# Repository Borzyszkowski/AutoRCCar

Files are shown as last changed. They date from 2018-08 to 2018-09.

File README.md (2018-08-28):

## Robotics in India: Intelligent Robot, Remote/Self-Driving Car
### by Bartłomiej Borzyszkowski, Poland
### Gdansk University of Technology (ETI) | Karunya Institute of Technology and Sciences (ET)

##### Python3 + OpenCV, Neural Networks, Raspberry Pi, Arduino Uno, Motor Driver, PiCamera, Ultrasonic sensor
##### Origin and inspiration for the project: https://github.com/hamuchiwa/AutoRCCar

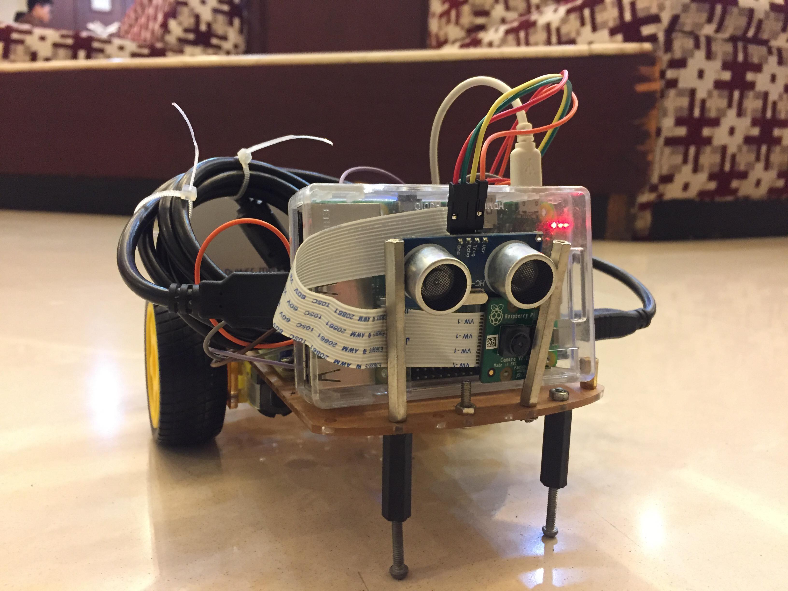
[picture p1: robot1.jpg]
robot

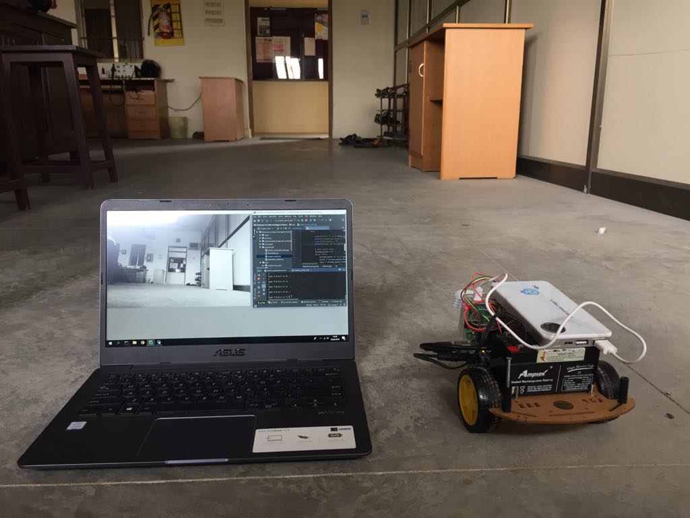
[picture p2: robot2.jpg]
computer+robot

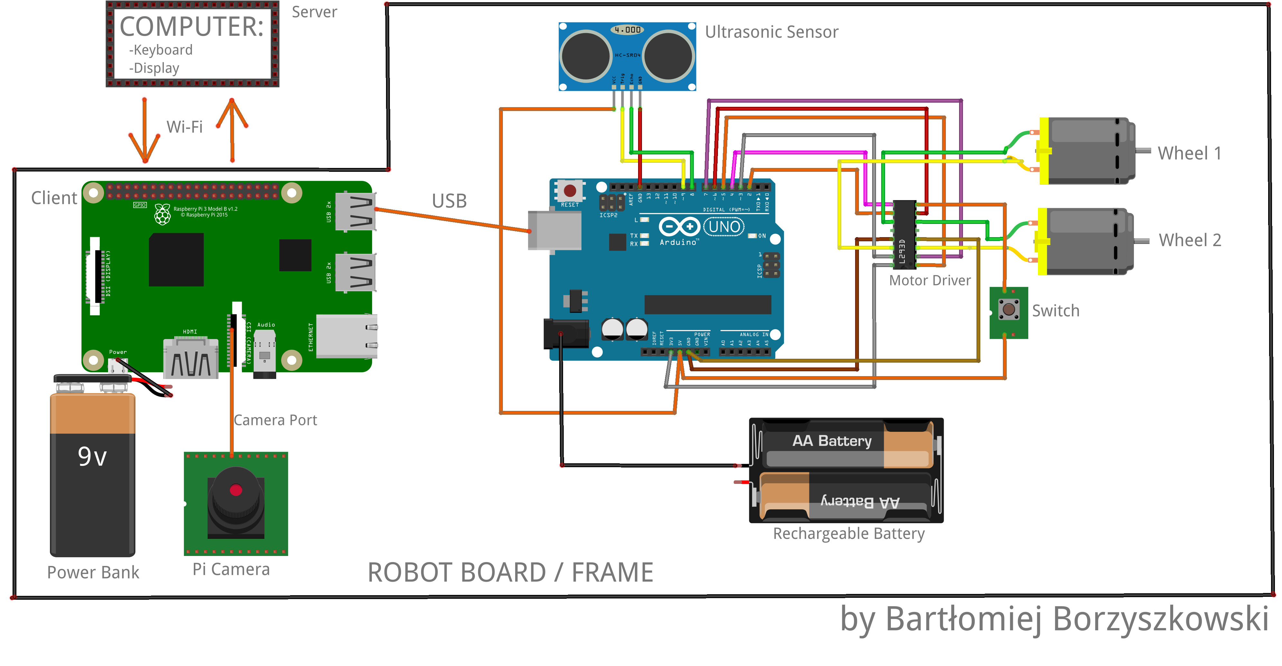
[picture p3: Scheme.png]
Scheme


This project builds a self-driving RC car using Raspberry Pi, Arduino and open source software. Raspberry Pi collects inputs from a camera module and an ultrasonic sensor, and sends data to a computer wirelessly. The computer processes input images and sensor data for object detection (stop sign and traffic light) and collision avoidance respectively. A neural network model runs on computer and makes predictions for steering based on input images. Predictions are then sent to the Arduino for RC car control. 
  
### For more information and details visit the folder "Multimedia and Sources".
### Don't stray too far from the presentation "Robotics in India" which explains the project.
[Presentation Robotics in India](https://github.com/Borzyszkowski/Robotics-in-India-Intelligent-Robot/blob/master/Multimedia%20and%20Sources/Robotics%20in%20India%20presentation.pdf)
 
### Setting up environment with Anaconda
  1. Install [`miniconda`](https://conda.io/miniconda.html) on your computer
  2. Create `auto-rccar` environment with all necessary libraries for this project  
     ```conda env create -f environment.yml```
     
  3. Activate `auto-rccar` environment  
     ```source activate auto-rccar```
  
  &ensp; To exit, simply close the terminal window. More info about managing Anaconda environment, please see [here](https://conda.io/docs/user-guide/tasks/manage-environments.html).
  
### About the files
**test/**  
  &emsp; &emsp; `rc_control_test.py`: RC car control with keyboard  
  &emsp; &emsp;  `stream_server_test.py`: video streaming from Pi to computer  
  &emsp; &emsp;  `ultrasonic_server_test.py`: sensor data streaming from Pi to computer  
  &emsp; &emsp;  **model_train_test/**  
      &emsp; &emsp;  &emsp; &emsp; `data_test.npz`: sample data  
      &emsp; &emsp;  &emsp; &emsp; `train_predict_test.ipynb`: a jupyter notebook that goes through neural network model in OpenCV3  
  
**raspberryPi/**    
  &emsp; &emsp;  `stream_client.py`:        stream video frames in jpeg format to the host computer  
  &emsp; &emsp;  `ultrasonic_client.py`:    send distance data measured by sensor to the host computer  
  
**arduino/**  
  &emsp; &emsp;  `rc_keyboard_control.ino`: control RC car controller  
  
**computer/**    
  &emsp; &emsp;  **cascade_xml/**  
      &emsp; &emsp;  &emsp; &emsp;  trained cascade classifiers  
  &emsp; &emsp;  **chess_board/**   
      &emsp; &emsp;  &emsp; &emsp;  images for calibration, captured by pi camera  
      
  &emsp; &emsp;  `picam_calibration.py`:     pi camera calibration  
  &emsp; &emsp;  `collect_training_data.py`: collect images in grayscale, data saved as `*.npz`  
  &emsp; &emsp;  `model.py`:                 neural network model  
  &emsp; &emsp;  `model_training.py`:        model training and validation  
  &emsp; &emsp;  `rc_driver_helper.py`:      helper classes/functions for `rc_driver.py`  
  &emsp; &emsp;  `rc_driver.py`:             receive data from raspberry pi and drive the RC car based on model prediction
  
**Traffic_signal**  
  &emsp; &emsp;  trafic signal sketch contributed by [@geek111](https://github.com/geek1111)

### How to drive
1. **Testing:** Flash `rc_keyboard_control.ino` to Arduino and run `rc_control_test.py` to drive the RC car with keyboard. Run `stream_server_test.py` on computer and then run `stream_client.py` on raspberry pi to test video streaming. Similarly, `ultrasonic_server_test.py` and `ultrasonic_client.py` can be used for sensor data streaming testing.   

2. **Pi Camera calibration (optional):** Take multiple chess board images using pi camera module at various angles and put them into **`chess_board`** folder, run `picam_calibration.py` and returned parameters from the camera matrix will be used in `rc_driver.py`.

3. **Collect training/validation data:** First run `collect_training_data.py` and then run `stream_client.py` on raspberry pi. Press arrow keys to drive the RC car, press `q` to exit. Frames are saved only when there is a key press action. Once exit, data will be saved into newly created **`training_data`** folder.

4. **Neural network training:** Run `model_training.py` to train a neural network model. Please feel free to tune the model architecture/parameters to achieve a better result. After training, model will be saved into newly created **`saved_model`** folder.

5. **Cascade classifiers training (optional):** Trained stop sign and traffic light classifiers are included in the **`cascade_xml`** folder, if you are interested in training your own classifiers, please refer to [OpenCV doc](http://docs.opencv.org/doc/user_guide/ug_traincascade.html) and this great [tutorial](http://coding-robin.de/2013/07/22/train-your-own-opencv-haar-classifier.html).

6. **Self-driving in action**: First run `rc_driver.py` to start the server on the computer, and then run `stream_client.py` and `ultrasonic_client.py` on raspberry pi.

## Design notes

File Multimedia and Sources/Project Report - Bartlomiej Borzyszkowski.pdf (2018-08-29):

DEVELOPMENT OF AN INTELLIGENT,

## REMOTE / SELF-DRIVING CAR

An IAESTE Internship Project Report submitted by

### BARTŁOMIEJ BORZYSZKOWSKI (IS18ET019)

Under the supervision of
Dr. K. Rajasekaran,
M.Tech., Ph.D., Professor

With the assistance of
Mr. J. Chinnadurai,

D.E.E.E

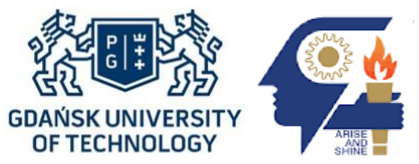
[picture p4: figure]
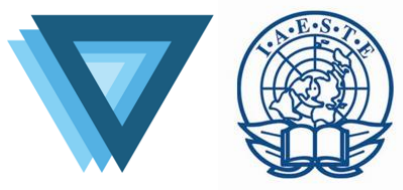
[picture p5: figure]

DEPARTMENT OF INSTRUMENTATION ENGINEERING

AUGUST 2018

BONAFIDE CERTIFICATE

This is to certify that this report entitled, “ CREATING AND DEVELOPING OF THE INTELLIGENT ROBOT, REMOTE / SELF-DRIVING CAR”, is a bonafide work of the following candidate from Gdansk University of Technology, Poland, who carried out the IAESTE Internship project work under my supervision during the academic year 2018-19 / Summer 2018.

BARTŁOMIEJ BORZYSZKOWSKI (IS18ET019)

Dissertation submitted in partial fulfillment of the requirements for the completion of the

IAESTE INTERNSHIP PROJECT

DEPARTMENT OF INSTRUMENTATION ENGINEERING

Supervisor
Dr. K. Rajasekaran,
M.Tech., Ph.D., Professor
Department of Instrumentation Engineering School of Engineering & Technology Karunya Institute of Technology and Sciences (A Deemed University)
Karunya Nagar, Coimbatore – 641 114

### ACKNOWLEDGEMENT

At the outset I express my gratitude to our eminent Professors – Prof. D.Sc. Ph.D. M.Sc.E.E. Jerzy Wtorek – Dean of the Faculty of Electronics,
Telecommunications and Informatics (https://pg.edu.pl/eti) and | | Prof. D.Sc. Ph.D. M.Sc.E.E.
Zdzisław Kowalczuk – Head of the Department | of Decision Systems and
Robotics (https://pg.edu.pl/katedra-systemow-decyzyjnych-i-robotyki) of Gdansk University of Technology, Poland for helping me in getting the Internship in India.

I thank IAESTE Poland, all the members of association and Gradient AI Science Club for their engagement, dedication and support in the project.

I wish to thank with deep sense of acknowledge to the Founders and Management of Karunya Institute of Technology & Sciences, Coimbatore for extending all facilities, providing me the educative infrastructure and learning ambience, which motivated me to a great extent.

I wish to express my sincere thanks to Dr. J. Dinesh Peter, Associate Professor, Head – IAESTE and Dr. P. Subha Hency Jose, Professor & Head of the Department of Instrumentation Engineering for their excellent encouragements in course of this work.

I take immense pleasure in conveying my thanks and deep sense of gratitude to my Supervisor Dr. K. Rajasekaran, Professor at the Department of Instrumentation Engineering, for his exhilarating supervision, timely suggestions and encouragement during all phases of this work. Also, I would like to thank all the Teaching faculty members and Supporting staff of our department for advising me whenever in need, cooperating with me and arranging the necessary facilities.

I would like to convey gratitude to my Parents whose support was always with me. Last but not the least I would like to thank my Friends and Others who directly or indirectly helped me in successful completion of this work.

IAESTE INTERNSHIP 2018

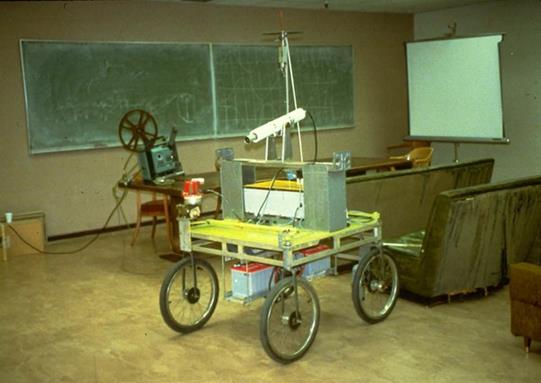
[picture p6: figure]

Department of IE / KITS, Coimbatore, India | Page 1

Abstract

Self-driving cars are vehicles in which human drivers are not required to take control to safely operate the vehicle. Also known as autonomous or „driverless” cars, they combine various sensors and software to control, navigate, and drive the vehicle. Self-driving technology is becoming increasingly common and could radically transform our transportation system (and by extension, our economy and society). The costs and benefits of self-driving cars are still largely hypothetical but in the past several years autonomous driving technologies have made a significant develop, giving a number of perspectives for the further progress.

Figure 1: Stanford Cart (1961) – the first „autonomous” vehicle

The idea of intelligent vehicle is multi-level, complex and contains a big number of different aspects. More information is needed to fully assess how autonomous cars impact drivers, the economy, equity environmental and public health. Recently, thanks to the artificial intelligence and deep learning methods, software engineers are able to develop solutions which give an answer for the big number of questions and difficulties.

As a result people create cars having different levels of intelligence and working with a diverse systems, sensors and environments. Partially-autonomous vehicles may require a human driver to intervene if the system encounters uncertainty or if the user simply wants to steer; fully-autonomous vehicles may not even offer a steering wheel.

Self-driving cars can be further distinguished as being „connected” or not, indicating whether they can communicate with other vehicles and/or infrastructure, such as next generation traffic lights.

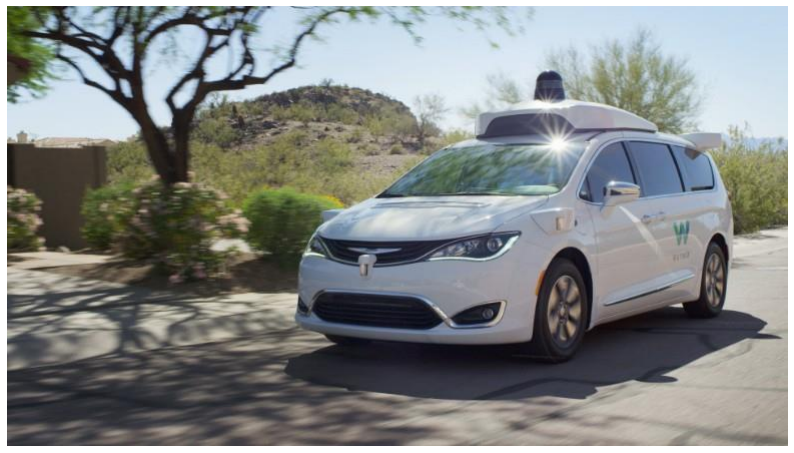
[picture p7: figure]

Figure 2: Waymo/Google – one of the most advanced self-driving cars

To make the development of self-driving cars easier, low cost, more accessible and prosperous small size models are widly used for the testing purposes. This solution guarantee the possibility to write the software working in the same way as in the real size models, compare the results and eliminate potential mistakes.

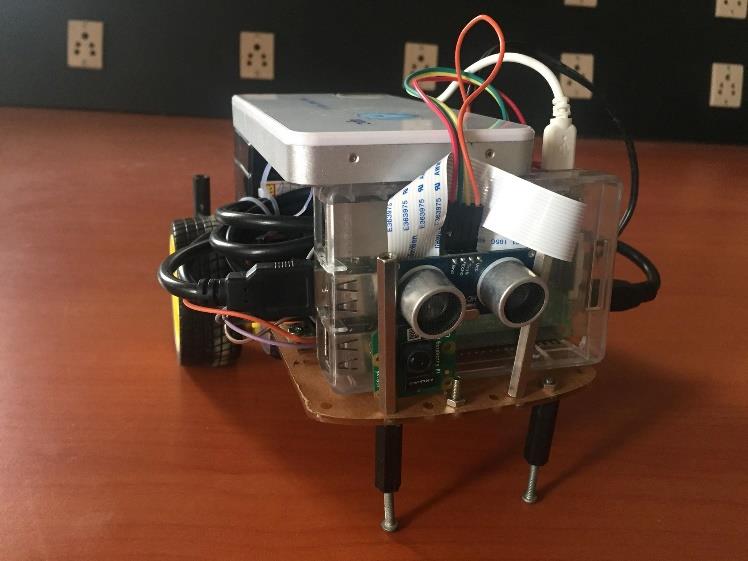
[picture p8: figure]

Figure 3: Intelligent Car project by Bartłomiej Borzyszkowski

Aim of the work

The aim of this project is to develop the model of partially-autonomous vehicle and reach the full-autonomous after future extensions.

The goal of the research is to design the construction of the intelligent car by using the Raspberry Pi, Arudino, ultrasonic sensor, camera and motor driver. Moreover, to write and develop the intelligent software using Python and C/C++ languages and design the „client – server” architecture between the used devices.

Robot overview

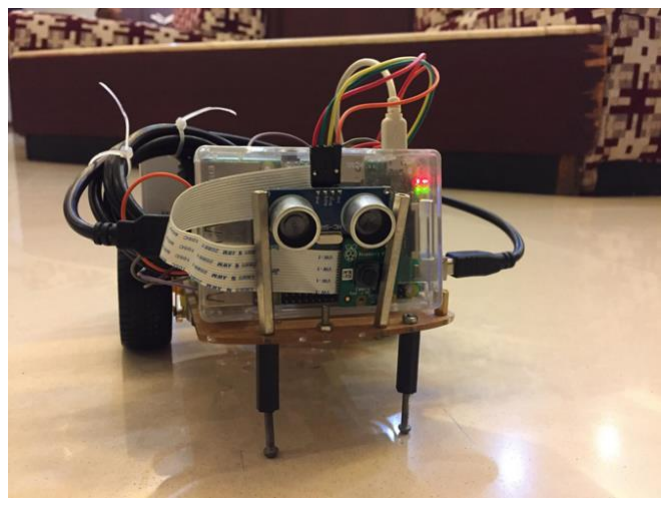
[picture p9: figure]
Equipment / C; omponents
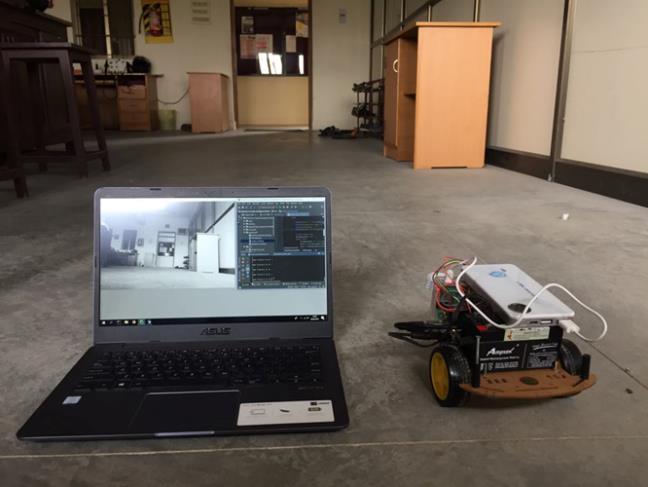
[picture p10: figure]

Figure 1: Front | Figure 2: Back and display

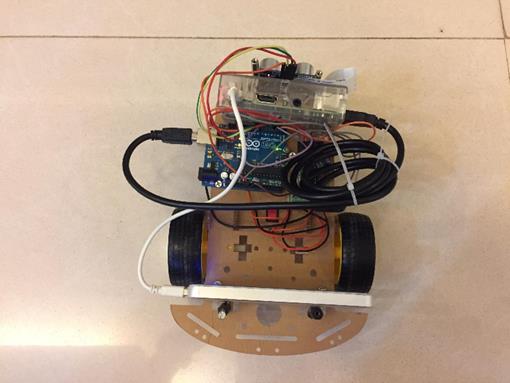
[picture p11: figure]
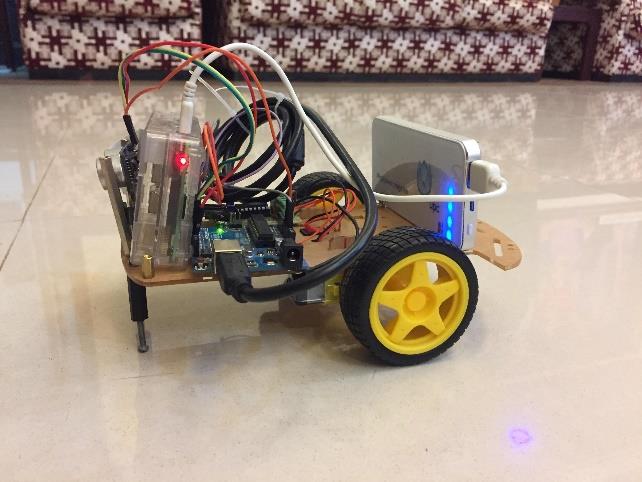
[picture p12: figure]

Figure 3: Top | Figure 4: Side

Project repository

The complete project repository, including the software, programs and libraries, multimedia and sources (videos and pictures from the laboratory), explanation of the project, schemes, problem solutions, robot construction and description of every particular device in the project is free and open to access, available on the GitHub profile under the link below:

github.com/Borzyszkowski/Robotics-in-India-Intelligent-Robot

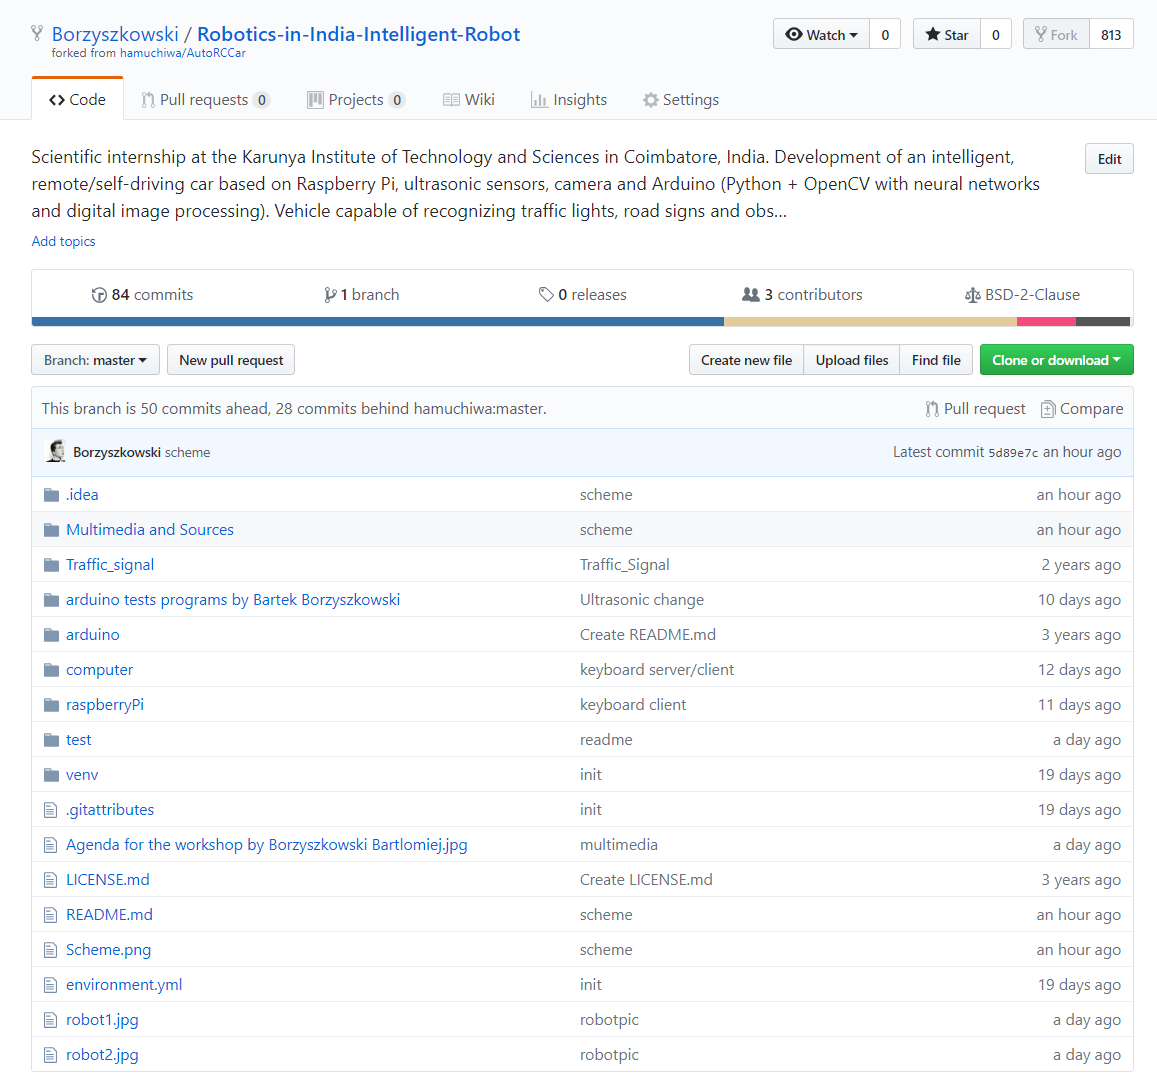
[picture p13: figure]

The project was inspired by the construction of autonomous car developed by Zheng Wang, available in the document below:

zhengludwig.wordpress.com/projects/self-driving-rc-car/

Functionality

The robot is an intelligent, partially-autonomous car, what means that user’s interve is required in the process but at the same time information collected from the environment make the robot capable to decide on its own and take some actions by itself.
The vehicle is able to move in four different directions – forward, backward, right, left and stop after pressing a corresponding button. The main functionality is steering by the user from the laptop keyboard (wireless connection/remote control).
Furthermore, the equipment with the ultrasonic sensor enables the robot to measure the distance from obstracles in the front and stop in case of possible collision. Thanks to the Pi camera the user has a real time display from the front of the robot on the laptop/PC screen. This solution allows the robot to be independent and wireless but at once the user has an access to steer the robot. In following steps of the project total autonomous and possibility to choose between self-drive or remote control steering is also possible.

Equipment / Components
- Raspberry Pi 3 Model B
- Camera desired for the Raspberry Pi
- Arduino UNO
- Laptop/PC
- Ultrasonic sensor HC-SR04
- Motor driver L293
- 2 separate motors and 2 wheels
- Power supply (power bank and an additional rechargeable battery)
- Robot board – car frame
- Cords/wires
- Switch button
- Soldering equipement
- Wi-Fi network
- External display
- Programming environment and software

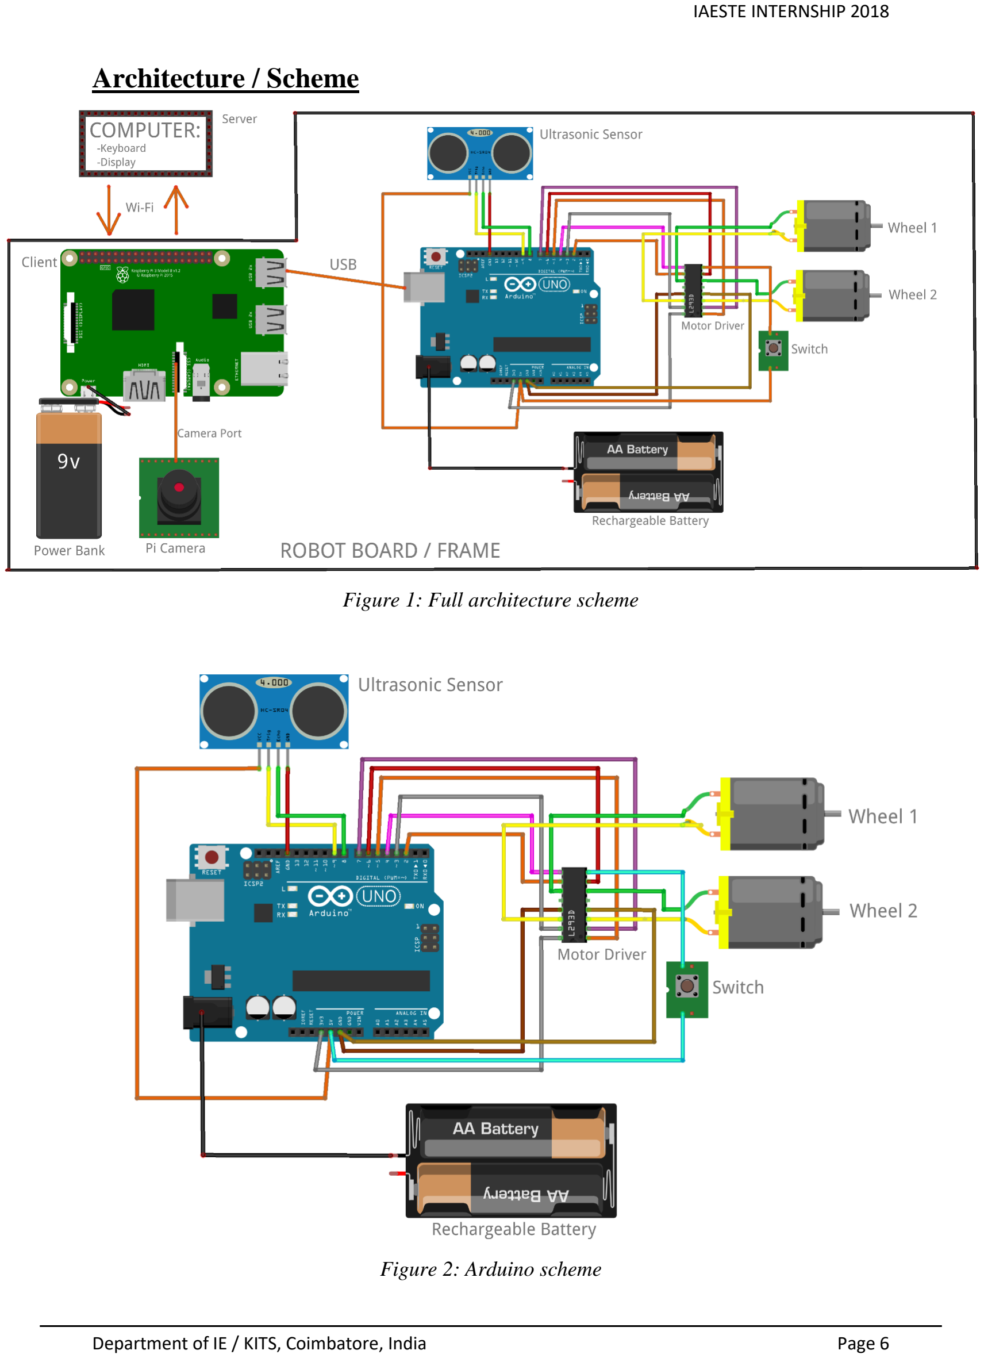
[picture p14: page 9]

Architecture / Scheme

Figure 1: Full architecture scheme

Figure 2: Arduino scheme

Hardware description

### 1. Computer

- Working as a server for the Raspberry Pi (client) via Wi-Fi
- Collecting information about steering from the keyboard and forwarding it to the Raspberry Pi
- Receiving video from the Raspberry Pi and showing the display

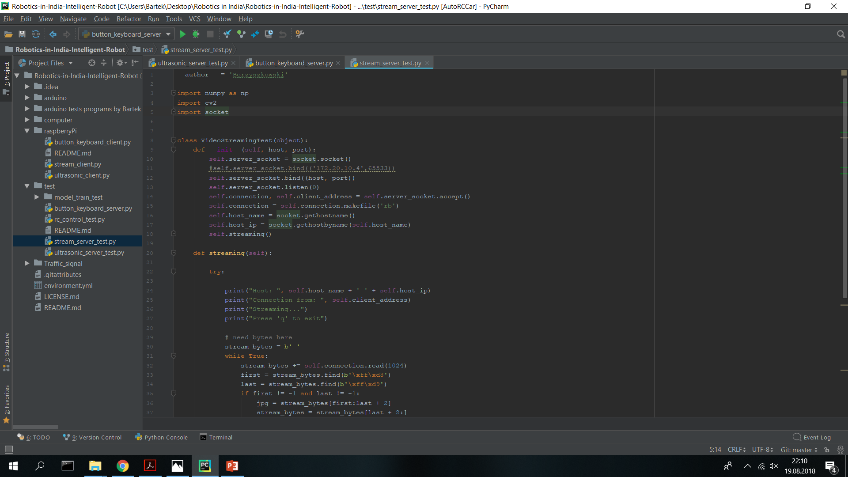
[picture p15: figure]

Figure 1: PyCharm Python Environment

### 2. Raspberry Pi

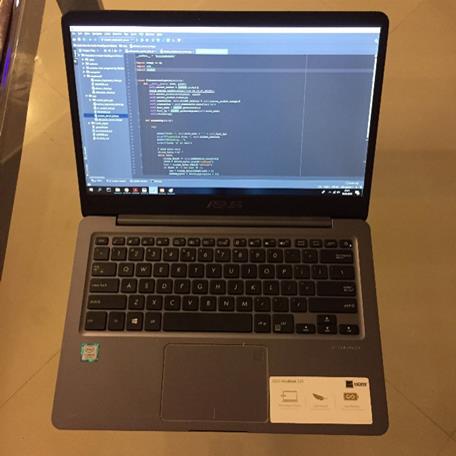
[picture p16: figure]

- Working as a client for the computer (server) via Wi-Fi
- Connected to the Arduino via USB
- Connected with the Pi camera
- Collecting information about steering from the computer (keyboard) and forwarding it to the Arduino
- Collecting data from the camera and sending it to the computer

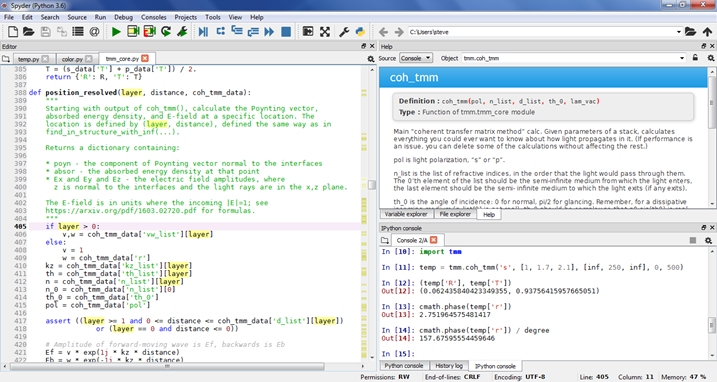
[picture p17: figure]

Figure 3: Spyder Python Environment

Figure 2: laptop used for the project

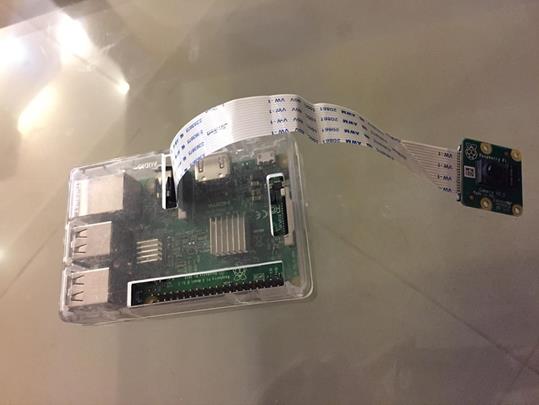
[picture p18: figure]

Figure 4: Raspberry Pi 3 model B with Pi Camera

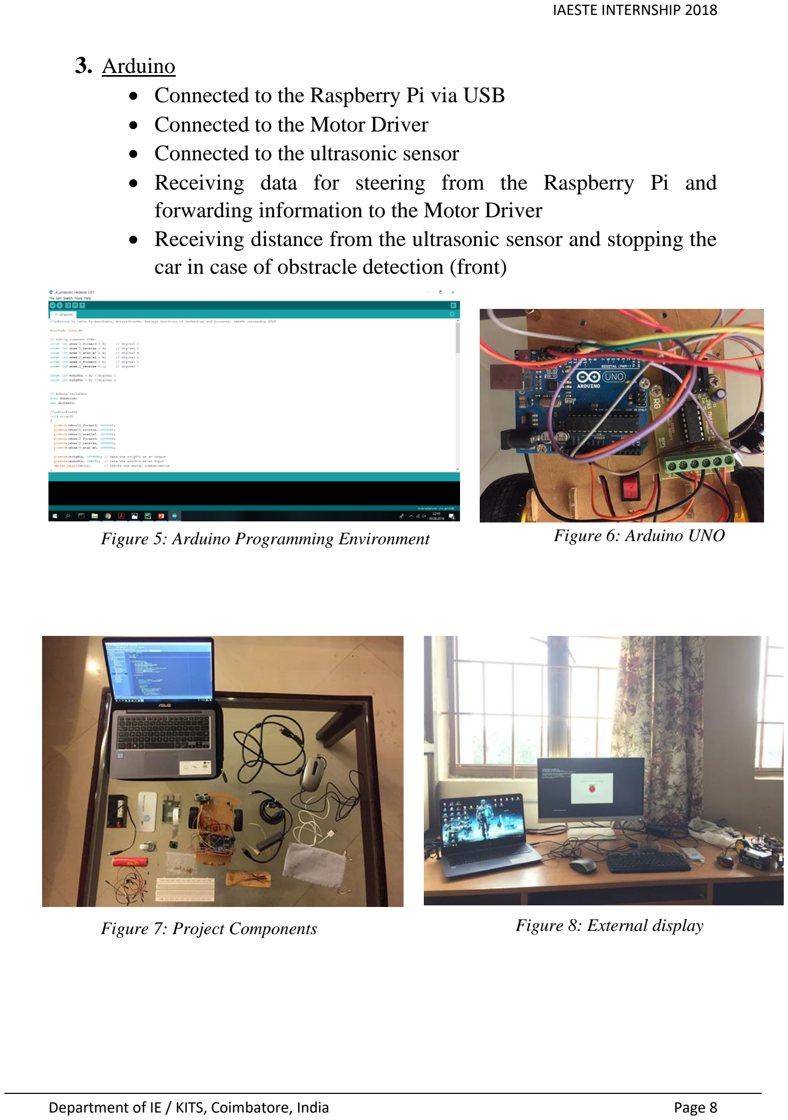
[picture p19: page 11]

### 3. Arduino

- Connected to the Raspberry Pi via USB
- Connected to the Motor Driver
- Connected to the ultrasonic sensor
- Receiving data for steering from the Raspberry Pi and forwarding information to the Motor Driver
- Receiving distance from the ultrasonic sensor and stopping the car in case of obstracle detection (front)

Figure 5: Arduino Programming Environment

Figure 7: Project Components

Figure 6: Arduino UNO

Figure 8: External display

Software description

In the current project version to achieve the required result five programs should run in the same time:

- Computer:
1. „button_keyboard_server.py”
2. „stream_server_test.py”
- Raspberry Pi:
3. „button_keyboard_client.py”
4. „stream_client.py”
- Arduino:
5. „_7._steering.ino”

For exchange of the data between the Raspberry Pi and the computer connection „serwer – client” is required. The recieved information about steering (from the keyboard) is transfered from the Raspberry Pi to the Arudino and further to the Motor Driver.

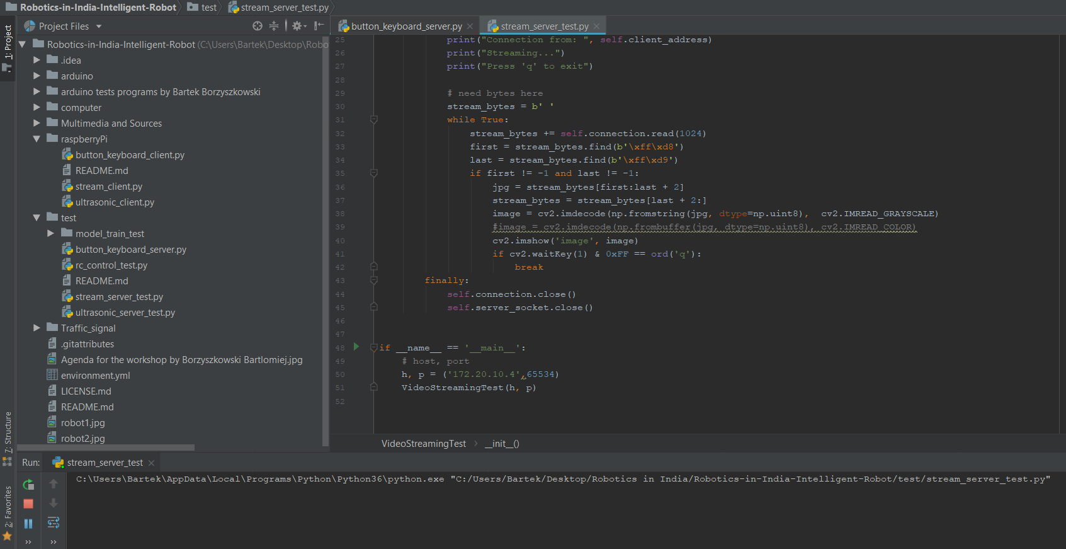
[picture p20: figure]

Figure 1: Project Software

Corresponding relation between devices allows to send the image from the camera to the Raspberry Pi and forward it further to the computer. Thanks to this solution, the user knows what is currently happening in front of the robot.

Besides the programs used in the project, GitHub repository is much more extended and gives more possibilities for different robot configurations (e.g. using the folder „arduino test programs by Bartek Borzyszkowski”). Moreover, folders including model training and programs developing and training the neural network allows the further evolution of the car.

Further develop
- Total autonomous
- Artificial intelligence, neural networks and image processing
- Road lines, signs and traffic lights recognition
- More advance steering (30, 45, 60 degree turn)
- Both kinds of control (self-drive and remote control) with balanced priorities or possibility to choose by the user

Conclusion / Sum up

To conclude, the aims of this internship were achieved successfully and are posted above as a result and source for future extensions and uses. Despite some difficulties, such as the camera streaming delay (solved by scaling down the resolution) the car works impressively.
Finally, intelligent vehicles are an important element in technological development and can contribute to the revolution on roads around the world. The design of the robot model created during the internship at the Department of Instrumentation Engineering, Karunya Institute of Technology and Sciences allows to observe the processes necessary to construct such a car, learn and draw the presented conclusions that will help in solving future potential problems.

Bartłomiej Borzyszkowski

Bibliography / References

Similar projects:

1. by Zheng Wang
- zhengludwig.wordpress.com/projects/self-driving-rc-car/
- github.com/hamuchiwa/AutoRCCar
2. by Ryan Zotti
- github.com/RyanZotti/Self-Driving-Car
3. by Yazeed Alrubyli
- becominghuman.ai/building-self-driving-rc-car-series-5-serverlesscontrol-using-computer-vision-fdf0d0136888 (https://becominghuman.ai/building-self-driving-rc-car-series-5-serverless-control-using-computer-vision-fdf0d0136888)
- github.com/yazeedalrubyli/SDRC
4. by Multunus
- github.com/multunus/autonomous-rc-car

Guides and specifications:

L293 Motor Driver:
- ti.com/lit/ds/symlink/l293.pdf
HC-SR04 Sensor:
- components101.com/ultrasonic-sensor-working-pinout-datasheet
- tutorials-raspberrypi.com/raspberry-pi-ultrasonic-sensor-hc-sr04/
- howtomechatronics.com/tutorials/arduino/ultrasonic-sensor-hc-sr04/ (https://howtomechatronics.com/tutorials/arduino/ultrasonic-sensor-hc-sr04/)
Pi Camera:
- projects.raspberrypi.org/en/projects/getting-started-with-picamera
- opencv-pythontutroals.readthedocs.io/en/latest/py_tutorials/py_calib3d/py_calibr ation/py_calibration.html (https://opencv-python-tutroals.readthedocs.io/en/latest/py_tutorials/py_calib3d/py_calibration/py_calibration.html)

Other sources:

- wired.com/story/guide-self-driving-cars/
- ucsusa.org/clean-vehicles/how-self-driving-carswork#.W4YvVegzZPZ (https://www.ucsusa.org/clean-vehicles/how-self-driving-cars-work#.W4YvVegzZPZ)

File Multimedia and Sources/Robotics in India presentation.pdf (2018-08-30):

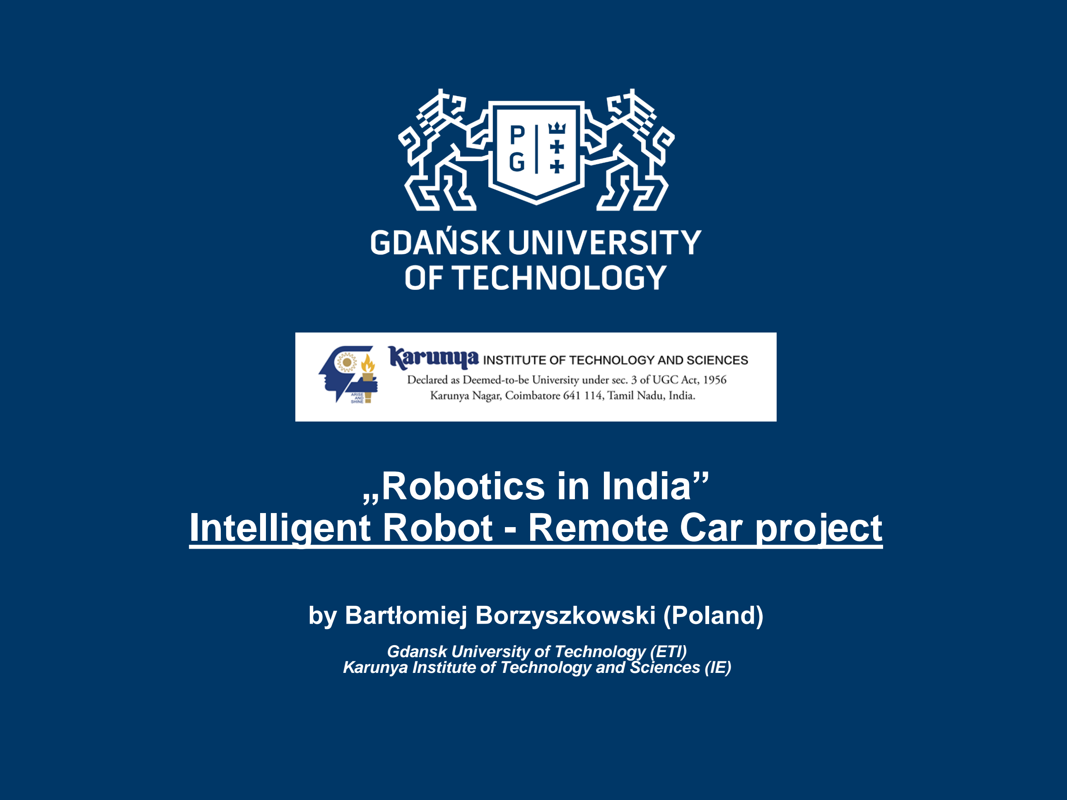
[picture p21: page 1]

## „Robotics in India” Intelligent Robot - Remote Car project

by Bartłomiej Borzyszkowski (Poland)

Gdansk University of Technology (ETI) Karunya Institute of Technology and Sciences (IE)

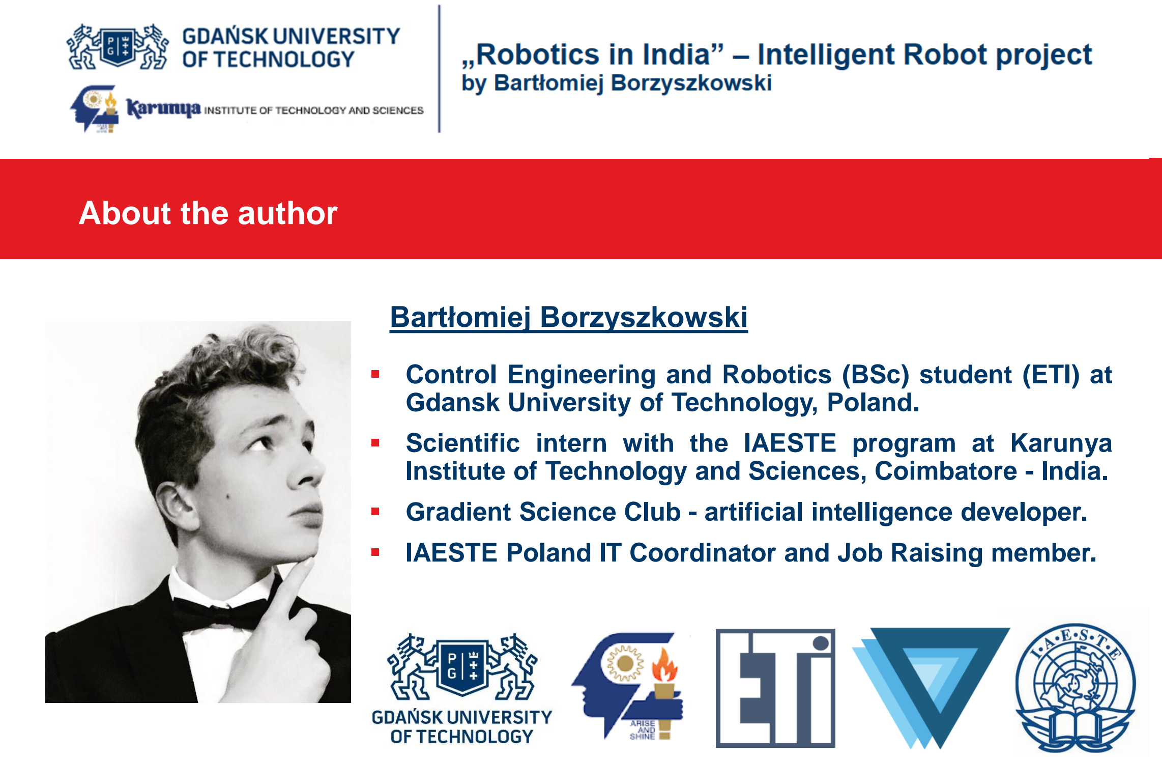
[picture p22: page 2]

„Robotics in India” – Intelligent Robot project
by Bartłomiej Borzyszkowski
- Control Engineering and Robotics (BSc) student (ETI) at Gdansk University of Technology, Poland.
- Scientific intern with the IAESTE program at Karunya Institute of Technology and Sciences, Coimbatore - India.
- Gradient Science Club - artificial intelligence developer.
- IAESTE Poland IT Coordinator and Job Raising member.

### About the author

Bartłomiej Borzyszkowski

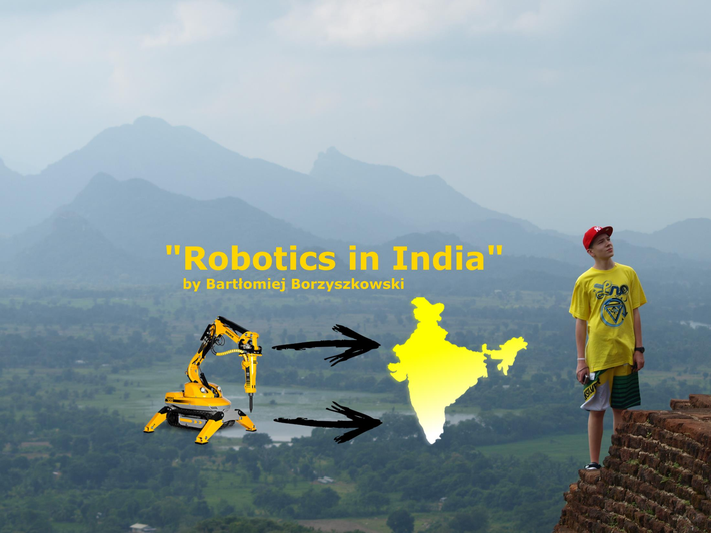
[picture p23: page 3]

„Robotics in India” – Intelligent Robot project
by Bartłomiej Borzyszkowski

### Robotics in India

„Robotics in India” – Intelligent Robot project
by Bartłomiej Borzyszkowski

### Gdańsk and Technology

„Robotics in India” – Intelligent Robot project
by Bartłomiej Borzyszkowski
- 8 week internship at the Karunya Instrumentation Department under the supervision of Dr. K. Rajasekaran with an assistance of Mr. J. Chinnadurai.
- Creating and developing of the intelligent robot, remote/self-driving car.
- Cooperation in the international
engineering team.

### Project introduction

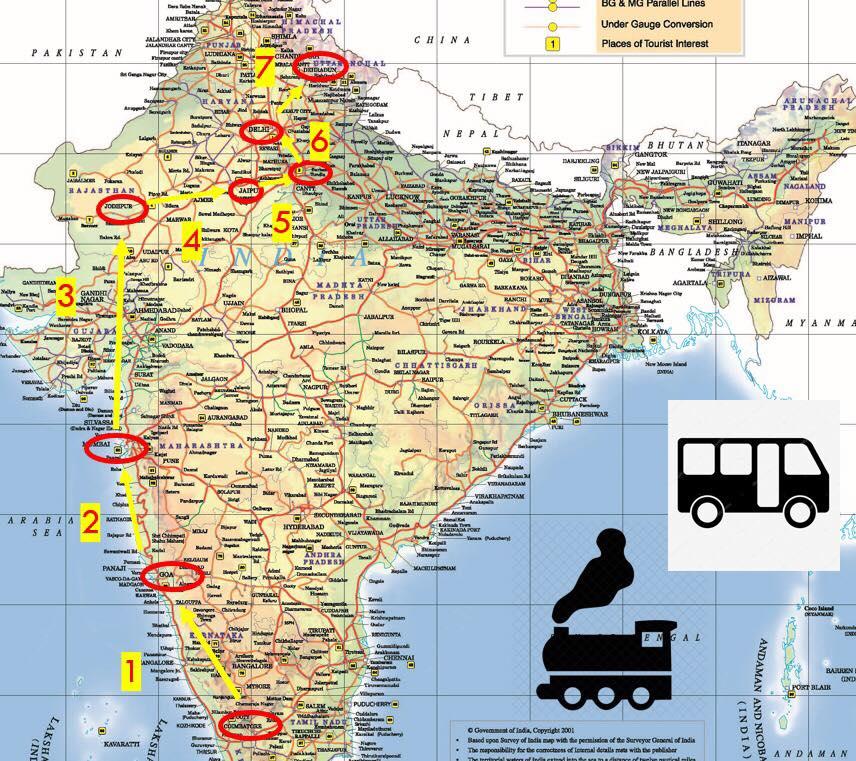
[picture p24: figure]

Besides the work:
- Over 3 week travel adventure including: Goa, Mumbai, Jodhpur, Jaipur, Delhi, Agra, Haridwar, Rishikesh, Ganges, Himalayas.
- Exploration of India, discovery of the rich culture, unique cuisine, wild nature and diverse environment of the country.

„Robotics in India” – Intelligent Robot project
by Bartłomiej Borzyszkowski

GitHub repository:
- github.com/Borzyszkowski/Robotics-in-India-Intelligent-Robot Crowdfunding campaigns and the full internship description:
- zrzutka.pl/robotics (Polish / English)

### Project introduction

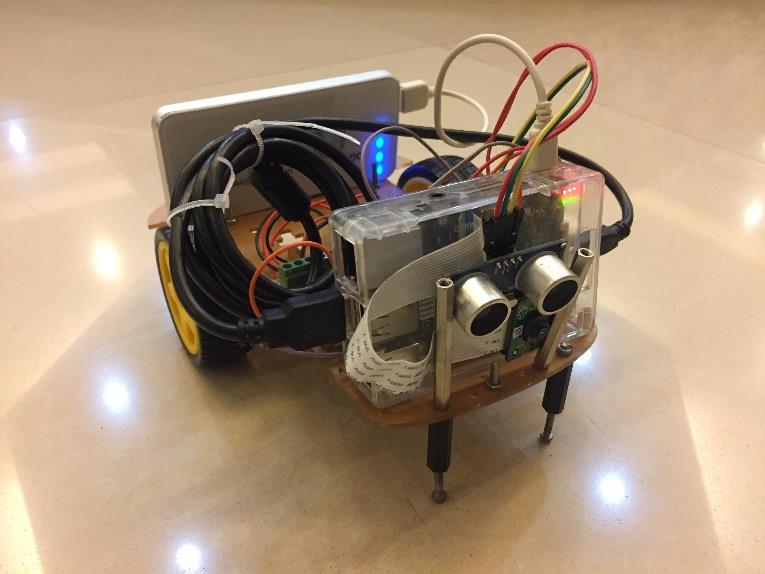
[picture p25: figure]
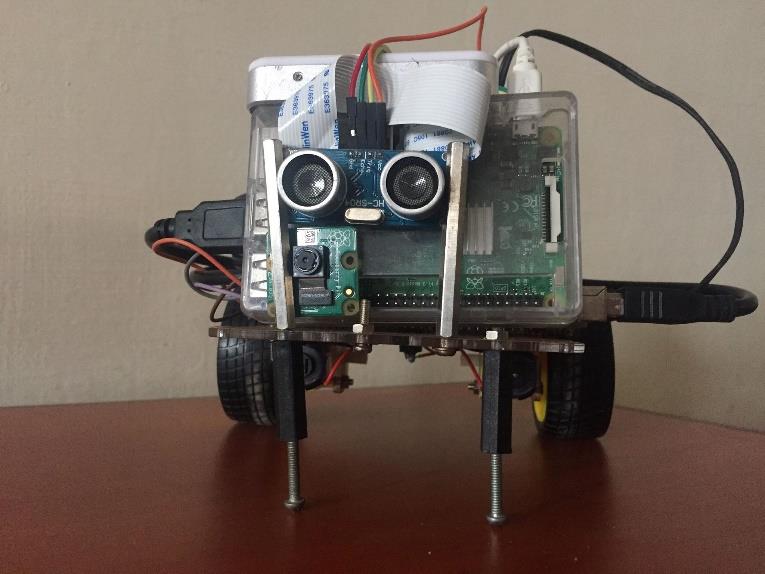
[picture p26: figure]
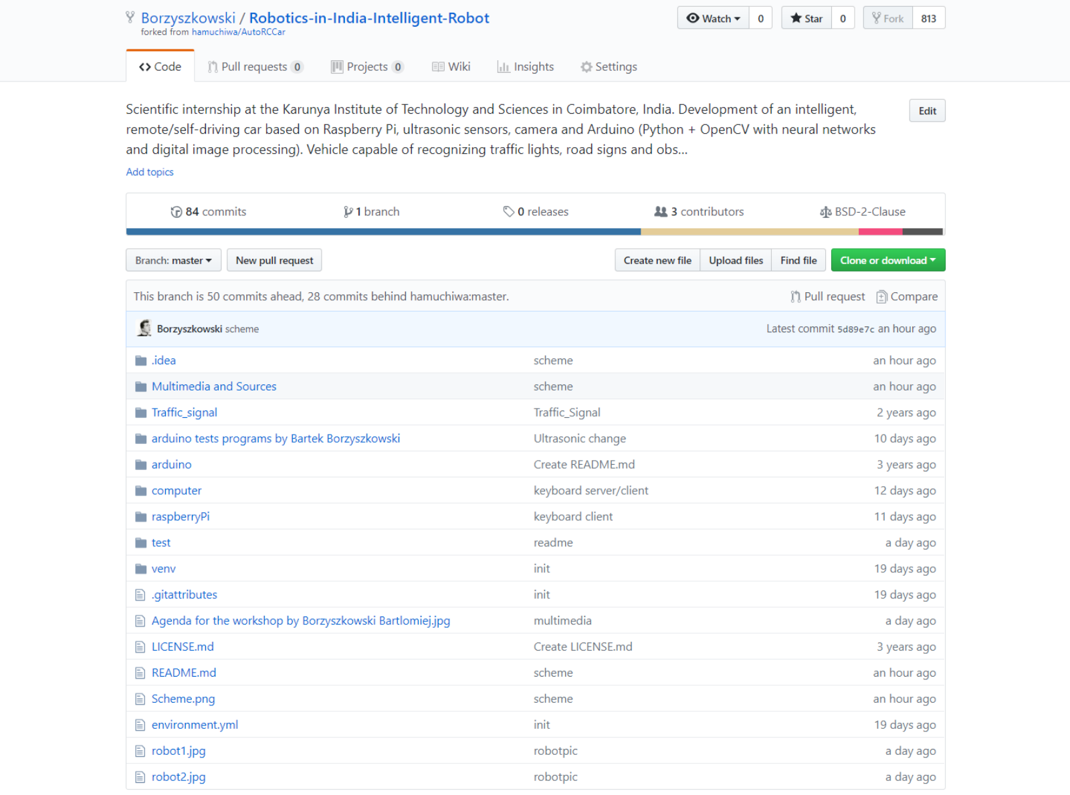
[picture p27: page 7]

„Robotics in India” – Intelligent Robot project
by Bartłomiej Borzyszkowski

### GitHub repository


„Robotics in India” – Intelligent Robot project
by Bartłomiej Borzyszkowski

### Robot overview


„Robotics in India” – Intelligent Robot project
by Bartłomiej Borzyszkowski

Zheng Wang Auto RC Car:
- github.com/hamuchiwa/AutoRCCar
- zhengludwig.wordpress.com/projects/self-driving-rc-car/

### Inspiration

„Robotics in India” – Intelligent Robot project
by Bartłomiej Borzyszkowski
- Remote control using laptop keyboard
- Camera display on the laptop
- Distance measurement thanks to ultrasonic sensor
- Steering (Forward, Backward, Right, Left, Stop)

### Functionality overview

„Robotics in India” – Intelligent Robot project
by Bartłomiej Borzyszkowski


Project elements:
- Raspberry Pi 3 Model B
- Camera desired for the Raspberry Pi
- Arduino UNO
- Laptop/PC
- Ultrasonic sensor HC-SR04
- Motor driver L293
- 2 separate motors and 2 wheels
- Power supply (Power Bank)
- Robot board – car frame
- Cords/wires and a switch button
- Soldering equipement
- Wi-Fi network
- External display
- Programming environment and software

### Construction details - components


„Robotics in India” – Intelligent Robot project
by Bartłomiej Borzyszkowski

### Construction details - architecture


„Robotics in India” – Intelligent Robot project
by Bartłomiej Borzyszkowski

Computer – laptop/PC:
- Working as a server for the Raspberry Pi (client) via Wi-Fi
- Collecting information about steering from the keyboard and forwarding it to the Raspberry Pi
- Receiving video from the Raspberry Pi and showing the display

### Construction details - Computer

„Robotics in India” – Intelligent Robot project
by Bartłomiej Borzyszkowski

Raspberry Pi:
- Working as a client for the computer (server) via Wi-Fi
- Connected to the Arduino via USB
- Connected with the Pi camera
- Collecting information about steering from the computer (keyboard) and forwarding it to the Arduino
- Collecting data from the camera and sending it to the computer

### Construction details - Raspberry Pi


„Robotics in India” – Intelligent Robot project
by Bartłomiej Borzyszkowski

Arduino:
- Connected to the Raspberry Pi via USB
- Connected to the Motor Driver
- Connected to the ultrasonic sensor
- Receiving data for steering from the Raspberry Pi and forwarding information to the Motor Driver
- Receiving distance from the ultrasonic sensor and stopping the car in case of obstracle detection (front)

### Construction details - Arduino


„Robotics in India” – Intelligent Robot project
by Bartłomiej Borzyszkowski

In the current project version to achieve the required result five programs should run in the same time.

### Software details

Raspberry Pi:
- 3.„button_keyboard_client.py”
- 4.„stream_client.py”

Computer:
- 1.„button_keyboard_server.py”
- 2.„stream_server_test.py”

Arduino:
- 5.„_7._steering.ino”

„Robotics in India” – Intelligent Robot project
by Bartłomiej Borzyszkowski

### Actual effect


„Robotics in India” – Intelligent Robot project
by Bartłomiej Borzyszkowski

### Actual effect


„Robotics in India” – Intelligent Robot project
by Bartłomiej Borzyszkowski

### Actual effect


„Robotics in India” – Intelligent Robot project
by Bartłomiej Borzyszkowski
- Real time data transfer (a significant number of operations at the same time)
- Camera video streaming delay (scaling down the resolution is required)
- Multi-level architecture (long way for the information to cover)
- Complex software (big numer of programs)

### Difficulties


## Despite difficulties the robot works!


„Robotics in India” – Intelligent Robot project
by Bartłomiej Borzyszkowski
- Total autonomous
- Artificial intelligence, neural networks and image processing
- Road lines, signs and traffic lights recognition
- More advance steering
- Both kinds of control (self-drive and remote control) with balanced priorities

### Further Develop


„Robotics in India” – Intelligent Robot project
by Bartłomiej Borzyszkowski

### Project sum up

To conclude, the aims of this internship were achieved successfully and are posted above as a result and source for future extensions and uses. The design of the robot model allows to observe the processes necessary to construct an intelligent car, learn and draw the presented conclusions that will help in solving future potential problems.

„Robotics in India” – Intelligent Robot project
by Bartłomiej Borzyszkowski

Similar projects:
- by Zheng Wang

### 1. zhengludwig.wordpress.com/projects/self-driving-rc-car/

### 2. github.com/hamuchiwa/AutoRCCar

- by Ryan Zotti

### 3. github.com/RyanZotti/Self-Driving-Car

- by Yazeed Alrubyli

### 4. becominghuman.ai/building-self-driving-rc-car-series-5-serverless-

control-using-computer-vision-fdf0d0136888 (https://becominghuman.ai/building-self-driving-rc-car-series-5-serverless-control-using-computer-vision-fdf0d0136888)

### 5. github.com/yazeedalrubyli/SDRC

- by Multunus

### 6. github.com/multunus/autonomous-rc-car

### Useful materials

„Robotics in India” – Intelligent Robot project
by Bartłomiej Borzyszkowski

Guides and specifications: L293 Motor Driver:
- ti.com/lit/ds/symlink/l293.pdf
HC-SR04 Sensor:
- components101.com/ultrasonic-sensor-working-pinout-datasheet
- tutorials-raspberrypi.com/raspberry-pi-ultrasonic-sensor-hc-sr04/
- howtomechatronics.com/tutorials/arduino/ultrasonic-sensor-hc-sr04/ Pi Camera:
- projects.raspberrypi.org/en/projects/getting-started-with-picamera
- opencv-python-tutroals.readthedocs.io/en/latest/py_tutorials/py_calib3d/py_calibration/py_calibra tion.html (https://opencv-python-tutroals.readthedocs.io/en/latest/py_tutorials/py_calib3d/py_calibration/py_calibration.html)

### Useful materials




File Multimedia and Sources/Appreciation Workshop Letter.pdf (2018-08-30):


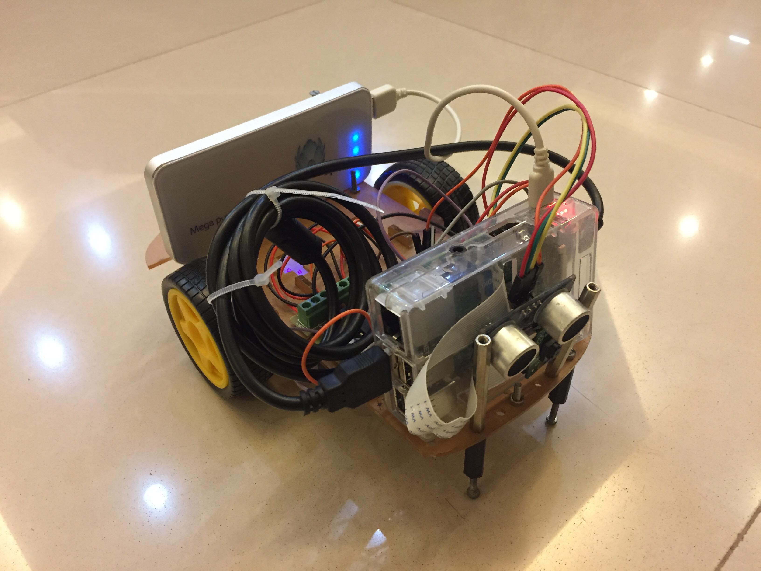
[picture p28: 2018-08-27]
Multimedia and Sources/Pictures/39543471_1578230922307506_2998542709171421184_n (1).jpg

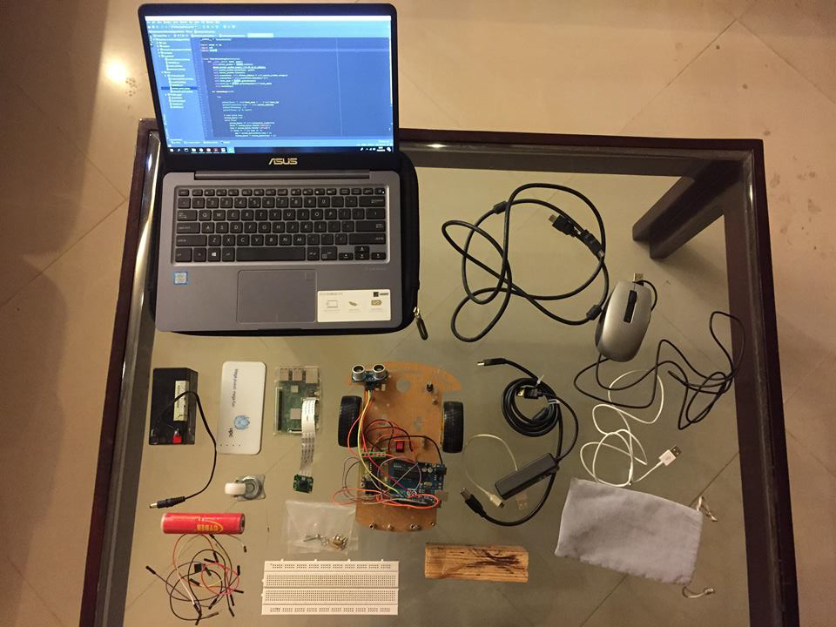
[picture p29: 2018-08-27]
Multimedia and Sources/Pictures/39580701_2191811251144103_3111954494603132928_n.jpg

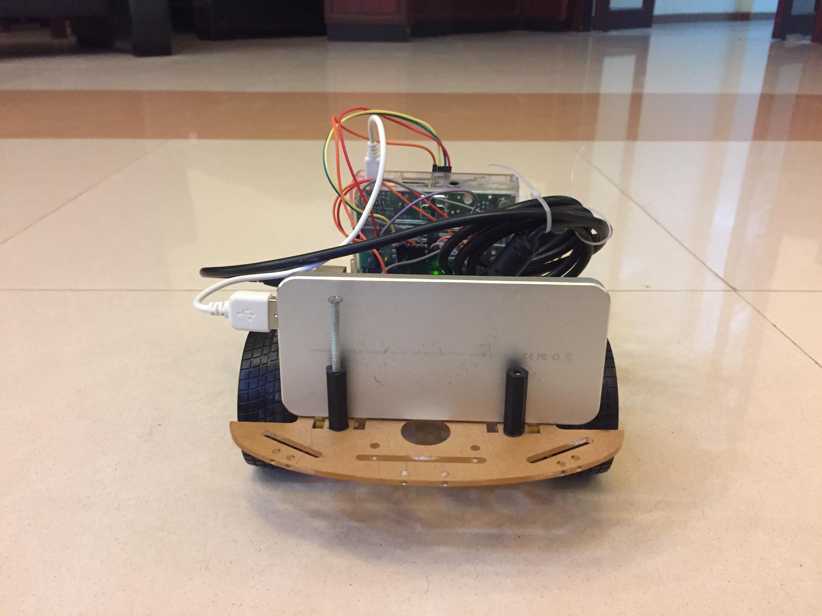
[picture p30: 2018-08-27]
Multimedia and Sources/Pictures/39441721_2158383207768617_6717952016338911232_n.jpg

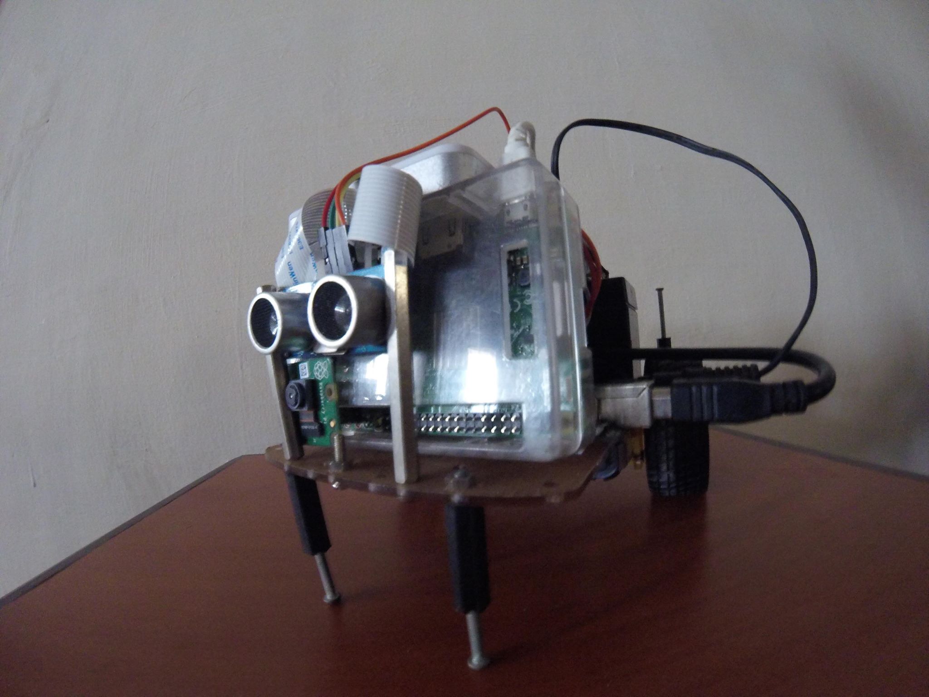
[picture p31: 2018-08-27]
Multimedia and Sources/Pictures/40116315_304409620111903_5201830549420769280_n.jpg

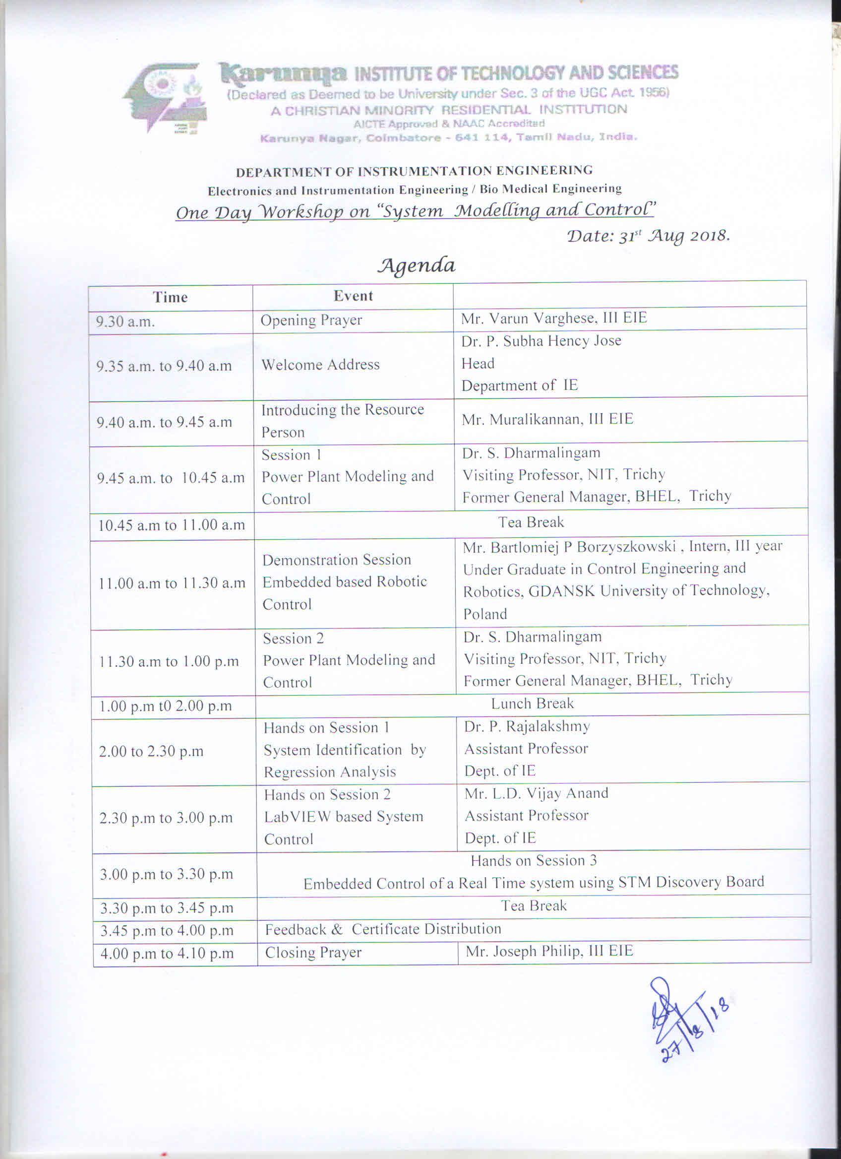
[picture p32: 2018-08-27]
Agenda for the workshop by Borzyszkowski Bartlomiej.jpg

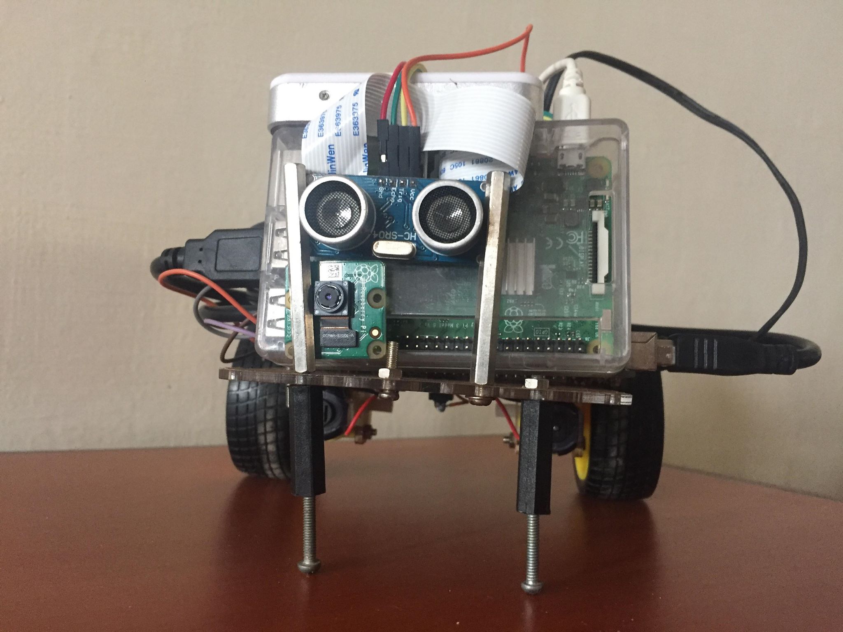
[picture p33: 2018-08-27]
Multimedia and Sources/Pictures/40128107_1885458551541114_3999889054056316928_n.jpg

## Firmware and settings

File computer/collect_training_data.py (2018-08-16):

__author__ = 'Borzyszkowski'

import numpy as np
import cv2
import serial
import pygame
from pygame.locals import *
import socket
import time
import os


class CollectTrainingData(object):
    
    def __init__(self, host, port, serial_port, input_size):

        self.server_socket = socket.socket()
        #self.server_socket.bind(('172.20.10.4', 0))
        self.server_socket.bind((host, port))
        self.server_socket.listen(0)

        # accept a single connection
        self.connection = self.server_socket.accept()[0].makefile('rb')

        # connect to a seral port
        self.ser = serial.Serial(serial_port, 115200, timeout=1)
        self.send_inst = True

        self.input_size = input_size

        # create labels
        self.k = np.zeros((4, 4), 'float')
        for i in range(4):
            self.k[i, i] = 1

        pygame.init()
        pygame.display.set_mode((250, 250))

    def collect(self):

        saved_frame = 0
        total_frame = 0

        # collect images for training
        print('Start collecting images...')
        e1 = cv2.getTickCount()
        image_array = np.zeros((1, 38400))
        label_array = np.zeros((1, 4), 'float')
        print("Start collecting images...")
        print("Press 'q' or 'x' to finish...")
        start = cv2.getTickCount()

        X = np.empty((0, self.input_size))
        y = np.empty((0, 4))

        # stream video frames one by one
        try:
            stream_bytes = b' '
            frame = 1
            while self.send_inst:
                stream_bytes += self.connection.read(1024)
                first = stream_bytes.find(b'\xff\xd8')
                last = stream_bytes.find(b'\xff\xd9')

                if first != -1 and last != -1:
                    jpg = stream_bytes[first:last + 2]
                    stream_bytes = stream_bytes[last + 2:]
                    image = cv2.imdecode(np.frombuffer(jpg, dtype=np.uint8), cv2.IMREAD_GRAYSCALE)
                    
                    # select lower half of the image
                    height, width = image.shape
                    roi = image[int(height/2):height, :]

                    cv2.imshow('image', image)

                    # reshape the roi image into a vector
                    temp_array = roi.reshape(1, int(height/2) * width).astype(np.float32)
                    
                    frame += 1
                    total_frame += 1

                    # get input from human driver
                    for event in pygame.event.get():
                        if event.type == KEYDOWN:
                            key_input = pygame.key.get_pressed()

                            # complex orders
                            if key_input[pygame.K_UP] and key_input[pygame.K_RIGHT]:
                                print("Forward Right")
                                X = np.vstack((X, temp_array))
                                y = np.vstack((y, self.k[1]))
                                saved_frame += 1
                                self.ser.write(chr(6).encode())

                            elif key_input[pygame.K_UP] and key_input[pygame.K_LEFT]:
                                print("Forward Left")
                                X = np.vstack((X, temp_array))
                                y = np.vstack((y, self.k[0]))
                                saved_frame += 1
                                self.ser.write(chr(7).encode())

                            elif key_input[pygame.K_DOWN] and key_input[pygame.K_RIGHT]:
                                print("Reverse Right")
                                self.ser.write(chr(8).encode())

                            elif key_input[pygame.K_DOWN] and key_input[pygame.K_LEFT]:
                                print("Reverse Left")
                                self.ser.write(chr(9).encode())

                            # simple orders
                            elif key_input[pygame.K_UP]:
                                print("Forward")
                                saved_frame += 1
                                X = np.vstack((X, temp_array))
                                y = np.vstack((y, self.k[2]))
                                self.ser.write(chr(1).encode())

                            elif key_input[pygame.K_DOWN]:
                                print("Reverse")
                                self.ser.write(chr(2).encode())

                            elif key_input[pygame.K_RIGHT]:
                                print("Right")
                                X = np.vstack((X, temp_array))
                                y = np.vstack((y, self.k[1]))
                                saved_frame += 1
                                self.ser.write(chr(3).encode())

                            elif key_input[pygame.K_LEFT]:
                                print("Left")
                                X = np.vstack((X, temp_array))
                                y = np.vstack((y, self.k[0]))
                                saved_frame += 1
                                self.ser.write(chr(4).encode())

                            elif key_input[pygame.K_x] or key_input[pygame.K_q]:

                                print("exit")
                                self.send_inst = False
                                self.ser.write(chr(0).encode())
                                self.ser.close()
                                break

                        elif event.type == pygame.KEYUP:
                            self.ser.write(chr(0).encode())

                    if cv2.waitKey(1) & 0xFF == ord('q'):
                        break

            # save data as a numpy file
            file_name = str(int(time.time()))
            directory = "training_data"
            if not os.path.exists(directory):
                os.makedirs(directory)
            try:
                np.savez(directory + '/' + file_name + '.npz', train=X, train_labels=y)
            except IOError as e:
                print(e)

            end = cv2.getTickCount()
            # calculate streaming duration
            time0 = (e2 - e1) / cv2.getTickFrequency()
            print('Streaming duration:', time0)

            print(train.shape)
            print(train_labels.shape)
            print('Total frame:', total_frame)
            print('Saved frame:', saved_frame)
            print('Dropped frame', total_frame - saved_frame)
            print("Streaming duration: , %.2fs" % ((end - start) / cv2.getTickFrequency()))
            print(X.shape)
            print(y.shape)
            print("Total frame: ", total_frame)
            print("Saved frame: ", saved_frame)
            print("Dropped frame: ", total_frame - saved_frame)

        finally:
            self.connection.close()
            self.server_socket.close()


if __name__ == '__main__':
    # host, port
    h, p = ('172.20.10.4', 65534)

    # serial port
    sp = "/dev/tty.usbmodem1421"

    # vector size, half of the image
    s = 120 * 320

    ctd = CollectTrainingData(h, p, sp, s)
    ctd.collect()

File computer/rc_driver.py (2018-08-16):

__author__ = 'Borzyszkowski'

import sys
import threading
import socketserver
import numpy as np


from model import NeuralNetwork
from rc_driver_helper import *

# distance data measured by ultrasonic sensor
sensor_data = None


class SensorDataHandler(socketserver.BaseRequestHandler):

    data = " "

    def handle(self):
        global sensor_data
        while self.data:
            self.data = self.request.recv(1024)
            sensor_data = round(float(self.data), 1)
            # print "{} sent:".format(self.client_address[0])
            print(sensor_data)


class VideoStreamHandler(socketserver.StreamRequestHandler):

    # h1: stop sign, measured manually
    # h2: traffic light, measured manually
    h1 = 5.5  # cm
    h2 = 5.5

    # load trained neural network
    nn = NeuralNetwork()
    nn.load_model("saved_model/nn_model.xml")

    obj_detection = ObjectDetection()
    rc_car = RCControl("/dev/tty.usbmodem1421")

    # cascade classifiers
    stop_cascade = cv2.CascadeClassifier("cascade_xml/stop_sign.xml")
    light_cascade = cv2.CascadeClassifier("cascade_xml/traffic_light.xml")

    d_to_camera = DistanceToCamera()
    d_stop_sign = 25
    d_light = 25

    stop_start = 0  # start time when stop at the stop sign
    stop_finish = 0
    stop_time = 0
    drive_time_after_stop = 0

    def handle(self):

        global sensor_data
        stream_bytes = b' '
        stop_flag = False
        stop_sign_active = True

        try:
            # stream video frames one by one
            while True:
                stream_bytes += self.rfile.read(1024)
                first = stream_bytes.find(b'\xff\xd8')
                last = stream_bytes.find(b'\xff\xd9')
                if first != -1 and last != -1:
                    jpg = stream_bytes[first:last + 2]
                    stream_bytes = stream_bytes[last + 2:]
                    gray = cv2.imdecode(np.frombuffer(jpg, dtype=np.uint8), cv2.IMREAD_GRAYSCALE)
                    image = cv2.imdecode(np.frombuffer(jpg, dtype=np.uint8), cv2.IMREAD_COLOR)

                    # lower half of the image
                    height, width = gray.shape
                    roi = gray[int(height/2):height, :]

                    # object detection
                    v_param1 = self.obj_detection.detect(self.stop_cascade, gray, image)
                    v_param2 = self.obj_detection.detect(self.light_cascade, gray, image)

                    # distance measurement
                    if v_param1 > 0 or v_param2 > 0:
                        d1 = self.d_to_camera.calculate(v_param1, self.h1, 300, image)
                        d2 = self.d_to_camera.calculate(v_param2, self.h2, 100, image)
                        self.d_stop_sign = d1
                        self.d_light = d2

                    cv2.imshow('image', image)
                    # cv2.imshow('mlp_image', roi)

                    # reshape image
                    image_array = roi.reshape(1, int(height/2) * width).astype(np.float32)

                    # neural network makes prediction
                    prediction = self.nn.predict(image_array)

                    # stop conditions
                    if sensor_data and int(sensor_data) < 30:
                        print("Stop, obstacle in front")
                        self.rc_car.stop()
                        sensor_data = None

                    elif 0 < self.d_stop_sign < 25 and stop_sign_active:
                        print("Stop sign ahead")
                        self.rc_car.stop()

                        # stop for 5 seconds
                        if stop_flag is False:
                            self.stop_start = cv2.getTickCount()
                            stop_flag = True
                        self.stop_finish = cv2.getTickCount()

                        self.stop_time = (self.stop_finish - self.stop_start) / cv2.getTickFrequency()
                        print("Stop time: %.2fs" % self.stop_time)

                        # 5 seconds later, continue driving
                        if self.stop_time > 5:
                            print("Waited for 5 seconds")
                            stop_flag = False
                            stop_sign_active = False

                    elif 0 < self.d_light < 30:
                        # print("Traffic light ahead")
                        if self.obj_detection.red_light:
                            print("Red light")
                            self.rc_car.stop()
                        elif self.obj_detection.green_light:
                            print("Green light")
                            pass
                        elif self.obj_detection.yellow_light:
                            print("Yellow light flashing")
                            pass

                        self.d_light = 30
                        self.obj_detection.red_light = False
                        self.obj_detection.green_light = False
                        self.obj_detection.yellow_light = False

                    else:
                        self.rc_car.steer(prediction)
                        self.stop_start = cv2.getTickCount()
                        self.d_stop_sign = 25

                        if stop_sign_active is False:
                            self.drive_time_after_stop = (self.stop_start - self.stop_finish) / cv2.getTickFrequency()
                            if self.drive_time_after_stop > 5:
                                stop_sign_active = True

                    if cv2.waitKey(1) & 0xFF == ord('q'):
                        print("car stopped")
                        self.rc_car.stop()
                        break
        finally:
            cv2.destroyAllWindows()
            sys.exit()


class Server(object):
    def __init__(self, host, port1, port2):
        self.host = host
        self.port1 = port1
        self.port2 = port2

    def video_stream(self, host, port):
        s = socketserver.TCPServer((host, port), VideoStreamHandler)
        s.serve_forever()

    def sensor_stream(self, host, port):
        s = socketserver.TCPServer((host, port), SensorDataHandler)
        s.serve_forever()

    def start(self):
        sensor_thread = threading.Thread(target=self.sensor_stream, args=(self.host, self.port2))
        sensor_thread.daemon = True
        sensor_thread.start()
        self.video_stream(self.host, self.port1)


if __name__ == '__main__':
    h, p1, p2 = '172.20.10.4', 65533, 65534

    ts = Server(h, p1, p2)
    ts.start()

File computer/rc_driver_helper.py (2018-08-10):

__author__ = 'Borzyszkowski'

import serial
import cv2
import math


class RCControl(object):

    def __init__(self, serial_port):
        self.serial_port = serial.Serial(serial_port, 115200, timeout=1)

    def steer(self, prediction):
        if prediction == 2:
            self.serial_port.write(chr(1).encode())
            print("Forward")
        elif prediction == 0:
            self.serial_port.write(chr(7).encode())
            print("Left")
        elif prediction == 1:
            self.serial_port.write(chr(6).encode())
            print("Right")
        else:
            self.stop()

    def stop(self):
        self.serial_port.write(chr(0).encode())


class DistanceToCamera(object):

    def __init__(self):
        # camera params
        self.alpha = 8.0 * math.pi / 180    # degree measured manually
        self.v0 = 119.865631204             # from camera matrix
        self.ay = 332.262498472             # from camera matrix

    def calculate(self, v, h, x_shift, image):
        # compute and return the distance from the target point to the camera
        d = h / math.tan(self.alpha + math.atan((v - self.v0) / self.ay))
        if d > 0:
            cv2.putText(image, "%.1fcm" % d,
                        (image.shape[1] - x_shift, image.shape[0] - 20),
                        cv2.FONT_HERSHEY_SIMPLEX, 0.7, (255, 255, 255), 2)
        return d


class ObjectDetection(object):

    def __init__(self):
        self.red_light = False
        self.green_light = False
        self.yellow_light = False

    def detect(self, cascade_classifier, gray_image, image):

        # y camera coordinate of the target point 'P'
        v = 0

        # minimum value to proceed traffic light state validation
        threshold = 150

        # detection
        cascade_obj = cascade_classifier.detectMultiScale(
            gray_image,
            scaleFactor=1.1,
            minNeighbors=5,
            minSize=(30, 30))

        # draw a rectangle around the objects
        for (x_pos, y_pos, width, height) in cascade_obj:
            cv2.rectangle(image, (x_pos + 5, y_pos + 5), (x_pos + width - 5, y_pos + height - 5), (255, 255, 255), 2)
            v = y_pos + height - 5
            # print(x_pos+5, y_pos+5, x_pos+width-5, y_pos+height-5, width, height)

            # stop sign
            if width / height == 1:
                cv2.putText(image, 'STOP', (x_pos, y_pos - 10), cv2.FONT_HERSHEY_SIMPLEX, 0.7, (0, 0, 255), 2)

            # traffic lights
            else:
                roi = gray_image[y_pos + 10:y_pos + height - 10, x_pos + 10:x_pos + width - 10]
                mask = cv2.GaussianBlur(roi, (25, 25), 0)
                (minVal, maxVal, minLoc, maxLoc) = cv2.minMaxLoc(mask)

                # check if light is on
                if maxVal - minVal > threshold:
                    cv2.circle(roi, maxLoc, 5, (255, 0, 0), 2)

                    # Red light
                    if 1.0 / 8 * (height - 30) < maxLoc[1] < 4.0 / 8 * (height - 30):
                        cv2.putText(image, 'Red', (x_pos + 5, y_pos - 5), cv2.FONT_HERSHEY_SIMPLEX, 0.5, (0, 0, 255), 2)
                        self.red_light = True

                    # Green light
                    elif 5.5 / 8 * (height - 30) < maxLoc[1] < height - 30:
                        cv2.putText(image, 'Green', (x_pos + 5, y_pos - 10), cv2.FONT_HERSHEY_SIMPLEX, 0.5, (0, 255, 0),2)
                        self.green_light = True

                    # yellow light
                    # elif 4.0/8*(height-30) < maxLoc[1] < 5.5/8*(height-30):
                    #    cv2.putText(image, 'Yellow', (x_pos+5, y_pos - 10), cv2.FONT_HERSHEY_SIMPLEX, 0.5, (0, 255, 255), 2)
                    #    self.yellow_light = True
        return v

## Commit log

2018-08-18 raspberry pi update
2018-08-18 Ultrasonic change
